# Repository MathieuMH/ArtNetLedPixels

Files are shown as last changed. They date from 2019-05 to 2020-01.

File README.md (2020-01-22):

# ArtNetLedPixels
This is a small project to drive up to +4000 WS28xx LED pixels. It is made for a local free family festival called Copacobana. Which takes place in Ghent (Belgium) every year at the end of June.
As a light operator I like to experiment with budget friendly equipment (like WS28xx leds), to create nice moderate effects. Our club stage is mainly for the afterparty.
This project was used to illuminate the logo of the stage.
The board receives it data from a lighting desk, in our situation (Chamsys MQ500). We mainly use the Art-Net protocol since its quite easy to adopt. The output is driven with the FastLED library.

# Required Hardware
The setup consists of the following hardware:
* Teensy 3.1 or 3.2 (there is basicly no difference for this project)
* Wiznet Wiz850io (LAN tranceived based on the WIZ5000)
* Carrierboard (refer to the ArtNet_WS2812B folder, board is drawn in KiCad 5)

# Output
The board has 12 outputs with screw terminal and one with solder terminal at R14.

# Contributors
Mathieu (THIEU.Gent)
Copacobana Festival http://www.copacobana.be

# License
MIT License

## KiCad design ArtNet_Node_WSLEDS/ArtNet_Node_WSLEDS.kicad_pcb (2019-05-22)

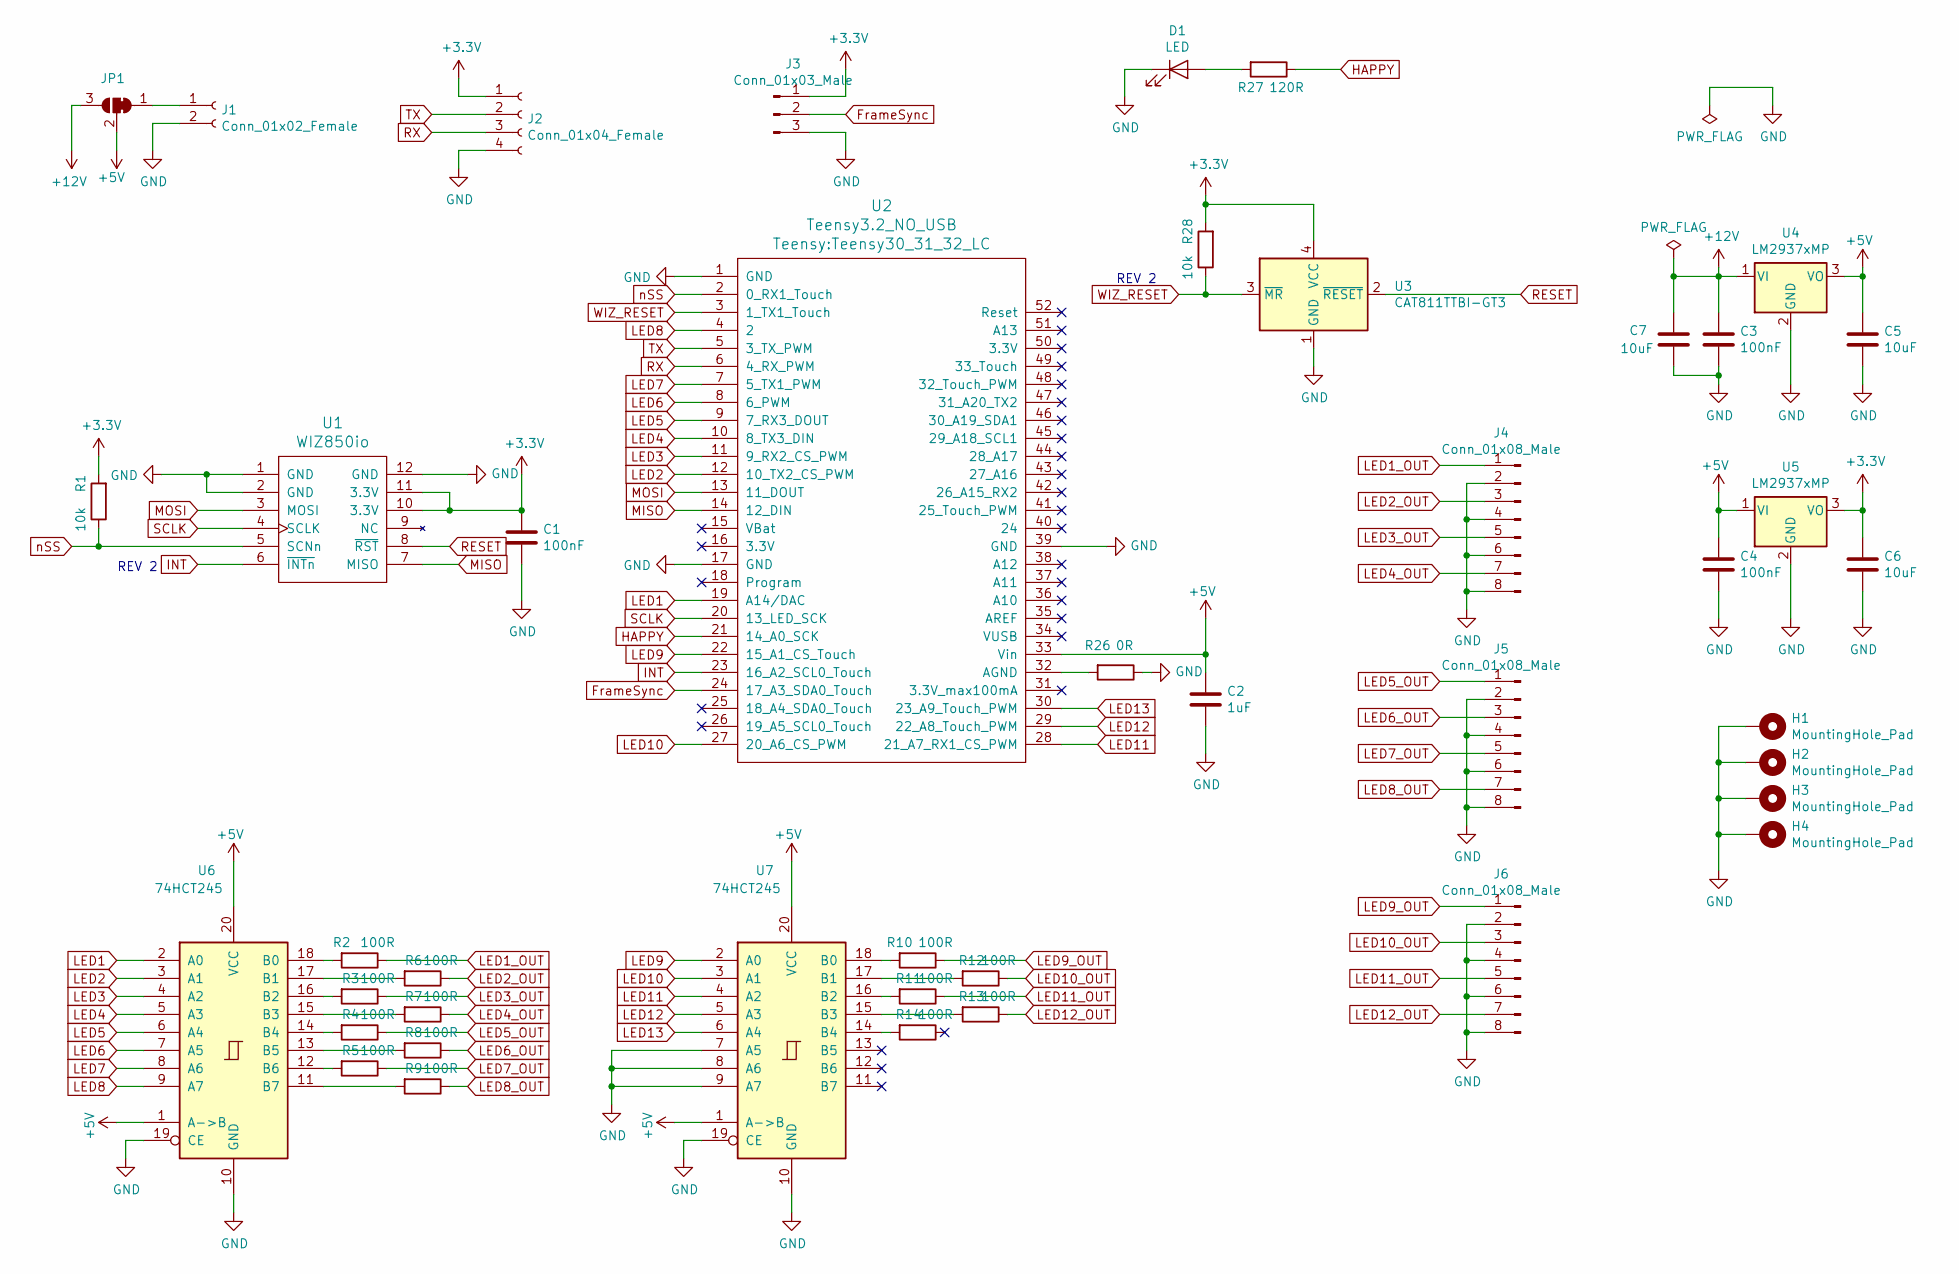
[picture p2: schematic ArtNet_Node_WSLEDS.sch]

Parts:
C1, C3, C4: 100nF; C_0805_HandSoldering
C2: 1uF; C_0805_HandSoldering
C5, C6, C7: 10uF; C_0805_HandSoldering
D1: LED; LED_1206_HandSoldering
H1, H2, H3, H4: MountingHole_Pad; MountingHole_4.3mm_M4_Pad
J1: Conn_01x02_Female; TerminalBlock_Phoenix_MPT-2.54mm_2pol
J2: Conn_01x04_Female; TerminalBlock_Phoenix_MPT-2.54mm_4pol
J3: Conn_01x03_Male; TerminalBlock_Phoenix_MPT-2.54mm_3pol
J4, J5, J6: Conn_01x08_Male; TerminalBlock_Phoenix_MPT-2.54mm_8pol
JP1: SolderJumper_3_Bridged12; SolderJumper-3_P1.3mm_Bridged12_Pad1.0x1.5mm_NumberLabels
R1, R28: 10k; R_1206_HandSoldering
R2, R3, R4, R5, R6, R7, R8, R9, R10, R11, R12, R13, R14: 100R; R_1206_HandSoldering
R26: 0R; R_1206_HandSoldering
R27: 120R; R_1206_HandSoldering
U1: WIZ850io
U2: Teensy3.2_NO_USB; Teensy30_31_32_LC
U3: CAT811TTBI-GT3; SOT-143
U4, U5: LM2937xMP; SOT-223-3_TabPin2
U6, U7: 74HCT245; SO-20_12.8x7.5mm_Pitch1.27mm

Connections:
+3V3: C1.1, C6.1, J2.1, J3.1, R1.2, R28.2, U1.10 (3.3V), U1.11 (3.3V), U3.4 (VCC), U5.3 (VO)
+5V: C2.1, C4.1, C5.1, JP1.2 (C), U2.33 (Vin), U4.3 (VO), U5.1 (VI), U6.1 (A->B), U6.20 (VCC), U7.1 (A->B), U7.20 (VCC)
+12V: C3.1, C7.1, JP1.3 (B), U4.1 (VI)
FrameSync: J3.2, U2.24 (17_A3_SDA0_Touch)
GND: C1.2, C2.2, C3.2, C4.2, C5.2, C6.2, C7.2, D1.1 (K), H1.1, H2.1, H3.1, H4.1, J1.2, J2.4, J3.3, J4.2, J4.4, J4.6, J4.8, J5.2, J5.4, J5.6, J5.8, J6.2, J6.4, J6.6, J6.8, R26.1, U1.1 (GND), U1.2 (GND), U1.12 (GND), U2.1 (GND), U2.17 (GND), U2.39 (GND), U3.1 (GND), U4.2 (GND), U5.2 (GND), U6.10 (GND), U6.19 (CE), U7.7 (A5), U7.8 (A6), U7.9 (A7), U7.10 (GND), U7.19 (CE)
HAPPY: R27.1, U2.21 (14_A0_SCK)
INT: U1.6 (~INTn), U2.23 (16_A2_SCL0_Touch)
LED1: U2.19 (A14/DAC), U6.2 (A0)
LED1_OUT: J4.1, R2.1
LED2: U2.12 (10_TX2_CS_PWM), U6.3 (A1)
LED2_OUT: J4.3, R6.1
LED3: U2.11 (9_RX2_CS_PWM), U6.4 (A2)
LED3_OUT: J4.5, R3.1
LED4: U2.10 (8_TX3_DIN), U6.5 (A3)
LED4_OUT: J4.7, R7.1
LED5: U2.9 (7_RX3_DOUT), U6.6 (A4)
LED5_OUT: J5.1, R4.1
LED6: U2.8 (6_PWM), U6.7 (A5)
LED6_OUT: J5.3, R8.1
LED7: U2.7 (5_TX1_PWM), U6.8 (A6)
LED7_OUT: J5.5, R5.1
LED8: U2.4 (2), U6.9 (A7)
LED8_OUT: J5.7, R9.1
LED9: U2.22 (15_A1_CS_Touch), U7.2 (A0)
LED9_OUT: J6.1, R10.1
LED10: U2.27 (20_A6_CS_PWM), U7.3 (A1)
LED10_OUT: J6.3, R12.1
LED11: U2.28 (21_A7_RX1_CS_PWM), U7.4 (A2)
LED11_OUT: J6.5, R11.1
LED12: U2.29 (22_A8_Touch_PWM), U7.5 (A3)
LED12_OUT: J6.7, R13.1
LED13: U2.30 (23_A9_Touch_PWM), U7.6 (A4)
MISO: U1.7 (MISO), U2.14 (12_DIN)
MOSI: U1.3 (MOSI), U2.13 (11_DOUT)
unnamed: D1.2 (A), R27.2
unnamed: J1.1, JP1.1 (A)
unnamed: R2.2, U6.18 (B0)
unnamed: R3.2, U6.16 (B2)
unnamed: R4.2, U6.14 (B4)
unnamed: R5.2, U6.12 (B6)
unnamed: R6.2, U6.17 (B1)
unnamed: R7.2, U6.15 (B3)
unnamed: R8.2, U6.13 (B5)
unnamed: R9.2, U6.11 (B7)
unnamed: R10.2, U7.18 (B0)
unnamed: R11.2, U7.16 (B2)
unnamed: R12.2, U7.17 (B1)
unnamed: R13.2, U7.15 (B3)
unnamed: R14.2, U7.14 (B4)
unnamed: R26.2, U2.32 (AGND)
RESET: U1.8 (~RST), U3.2 (~RESET)
RX: J2.3, U2.6 (4_RX_PWM)
SCLK: U1.4 (SCLK), U2.20 (13_LED_SCK)
TX: J2.2, U2.5 (3_TX_PWM)
WIZ_RESET: R28.1, U2.3 (1_TX1_Touch), U3.3 (~MR)
nSS: R1.1, U1.5 (SCNn), U2.2 (0_RX1_Touch)

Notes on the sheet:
REV 2

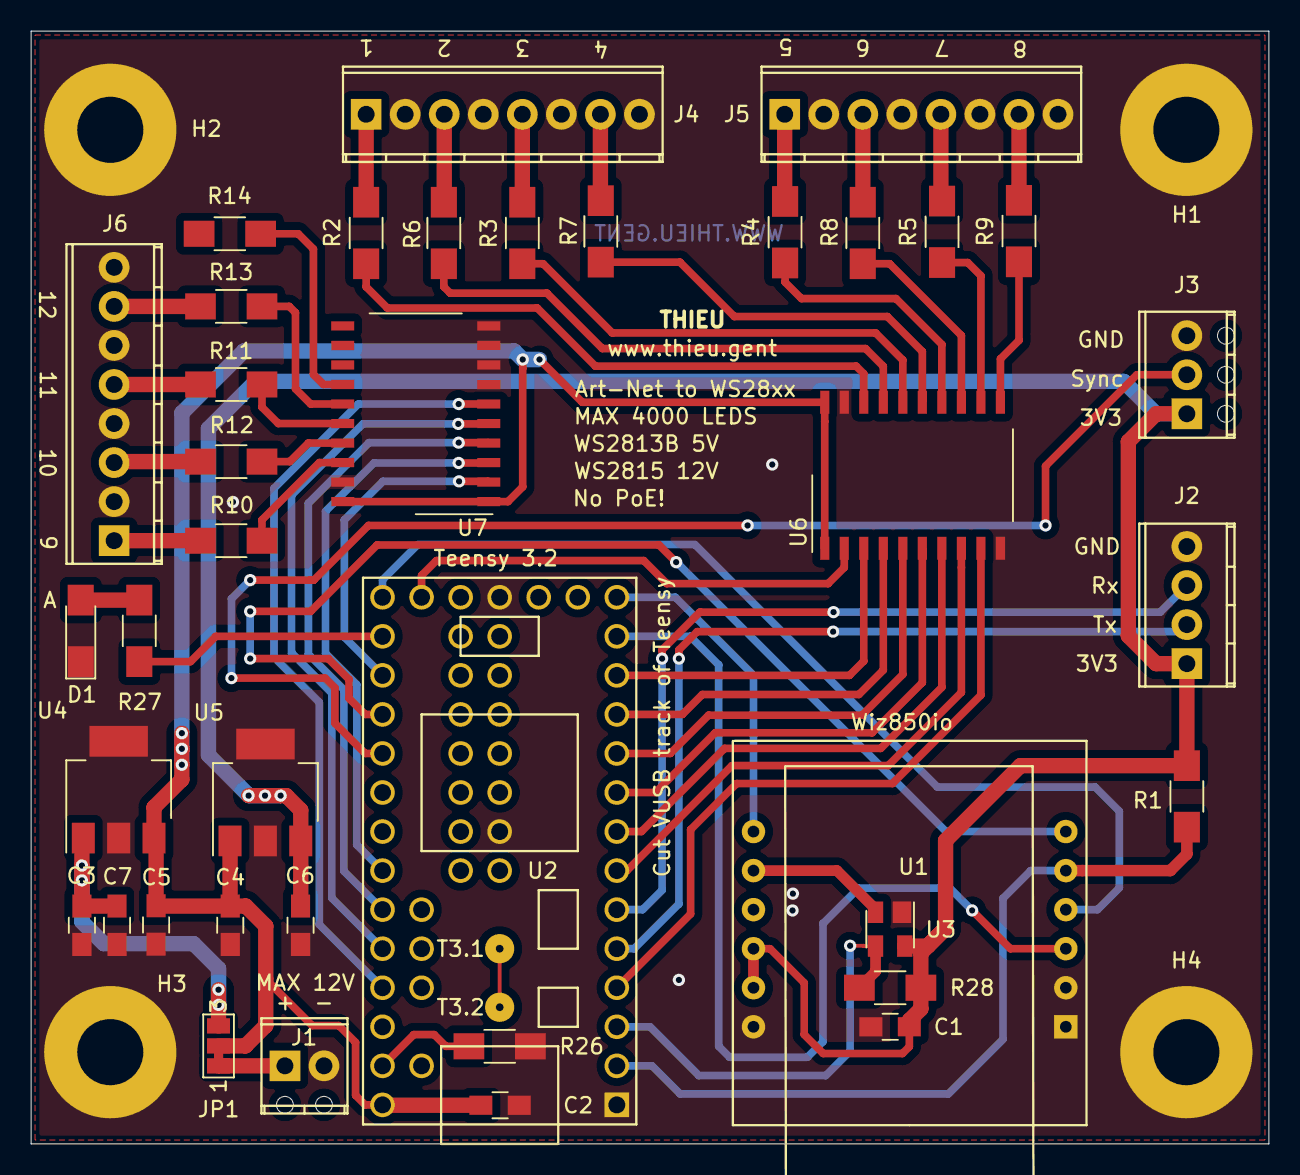
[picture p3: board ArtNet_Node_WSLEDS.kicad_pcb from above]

Board: 2 copper layers, 80.5 x 72.4 mm, 43 parts (0 on the bottom side), 56 nets.

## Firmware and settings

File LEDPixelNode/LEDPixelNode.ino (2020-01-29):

/*H**********************************************************************
* FILENAME :        LEDPixelNode.ino         DESIGN REF: LPXN
*
* DESCRIPTION :
*       This code will receive multiple univers via Art-Net and send
*       it to a multiple WS28xx LED strips.
*
* NOTES :
*       This code is optimized to run on a Teensy 3.x
*       A Wiz850io (or legacy Wiz820io) is used to receive the UPD data.
*       A THIEU designed carrier board to connect everything.
*       
* GIT :
*       https://github.com/MathieuMH/ArtNetLedPixels
*
* AUTHOR :    Mathieu Hebbrecht       START DATE :    22 Januari 2020
*
* CHANGES :
* REF NO  VERSION   DATE        WHO     DETAIL
* LPXN    00.01     22/01/2020  MHT     Initial version
*
* LICENSE :
* MIT license, see the LICENSE file for details
*H*/

#define FASTLED_ALLOW_INTERRUPTS 0
//#define USE_OCTOWS2811
//#include <OctoWS2811.h>
#include <FastLED.h>
#include <Artnet.h>

// --- PIN DEFINITIONS ---
#define LED1          14
#define LED2          10
#define LED3          9
#define LED4          8
#define LED5          7
#define LED6          6
#define LED7          5
#define LED8          2
#define LED9          15
#define LED10         20
#define LED11         21
#define LED12         22
#define LED13         23
#define WIZ_CS        0
#define WIZ_RESET     1
#define WIZ_INT       16
#define HAPPY_LED     13
#define FRAME_SYNC    17
#define UART_RX       4
#define UART_TX       3

// --- GENERIC DEFINITIONS
#define DEBUG                 0       // 0=only operation commands, no debug ; 1=high level debug ; 2=low level debug
#define RELEASE               0       // Significant changes marker (FEATURES)
#define VERSION               1       // Minor change marker (BUG FIXES)
#define HAPPY_PULSE           1000    // HAPPY LED Flash interval
#define NUM_LEDS_PER_STRIP    40      // Number of pixels in each LEDS strip (= output)
#define NUM_LED_STRIPS        1       // Number of strips connected

int inByte = 0;
long previousMillis = 0;
int ledState = HIGH;

// --- FastLED Settings
//CRGB leds[NUM_LEDS_PER_STRIP];
const int numLeds = NUM_LED_STRIPS * NUM_LED_STRIPS;
CRGB leds[numLeds];

// --- Art-Net Settings
Artnet artnet;
int startUniverse = 0;          // Default Artnet universe (in most cases this is 0, but some software require 1 as first)
int previousDataLength = 0;

// --- Network settings
//byte ip[] = {2, 9, 200, 15};
byte broadcast[] = {2, 255, 255, 255};
byte mac[] = {0x72, 0x67, 0xF0, 0xeb, 0x33, 0x30};

void setup()
{
  // - Set pin directions
  //pinMode(HAPPY_LED, OUTPUT);
  pinMode(WIZ_RESET, OUTPUT);
  //pinMode(WIZ_INT, INPUT);
  //pinMode(FRAME_SYNC, INPUT);

    // Port Init
  digitalWrite(WIZ_RESET, LOW);   //Start Wiz850io Reset
  delay(5);
  digitalWrite(WIZ_RESET, HIGH);   //End Wiz850io Reset
  
  // - Serial Init
  Serial.begin(115200);     // For debug and setup
  delay(5);
  Serial.print("LedPixelNode v");
  Serial.print(RELEASE);
  Serial.println("." + VERSION);
  Serial.println( "Compiled: " __DATE__ ", " __TIME__ ", " __VERSION__);
  
  if(DEBUG > 0)
  {  
    while (!Serial) 
    {
      ; // wait for serial port to connect. Needed for native USB port only
    }
    Serial.print("Debug Level is set to: ");
    Serial.println(DEBUG);
  }

  artnet.begin(mac);
  artnet.setBroadcast(broadcast);
  delay(10);

  //Check if Wiz850io is present
  if (Ethernet.hardwareStatus() == EthernetNoHardware) {
    Serial.println("No Wiz850io (or 820io) found. Sorry, can't run without hardware. :(");
    while (true) {
      delay(1); // do nothing, no point running without Ethernet hardware
    }
  }
  if (Ethernet.linkStatus() == LinkOFF) {
    Serial.println("Ethernet cable is not connected.");
  }

    // - FastLed Setup
  FastLED.addLeds<WS2811, LED2>(leds, 0, NUM_LEDS_PER_STRIP);
  //FastLED.addLeds<WS2811, LED2>(leds, NUM_LEDS_PER_STRIP, NUM_LEDS_PER_STRIP);
  //FastLED.addLeds<WS2811, LED3>(leds, NUM_LEDS_PER_STRIP, NUM_LEDS_PER_STRIP);
  //FastLED.addLeds<WS2811, LED4>(leds, NUM_LEDS_PER_STRIP, NUM_LEDS_PER_STRIP);
//  FastLED.addLeds<WS2812B, LED5>(leds, NUM_LEDS_PER_STRIP, NUM_LEDS_PER_STRIP);
//  FastLED.addLeds<WS2812B, LED6>(leds, NUM_LEDS_PER_STRIP, NUM_LEDS_PER_STRIP);
//  FastLED.addLeds<WS2812B, LED7>(leds, NUM_LEDS_PER_STRIP, NUM_LEDS_PER_STRIP);
//  FastLED.addLeds<WS2812B, LED8>(leds, NUM_LEDS_PER_STRIP, NUM_LEDS_PER_STRIP);
//  FastLED.addLeds<WS2812B, LED9>(leds, NUM_LEDS_PER_STRIP, NUM_LEDS_PER_STRIP);
//  FastLED.addLeds<WS2812B, LED10>(leds, NUM_LEDS_PER_STRIP, NUM_LEDS_PER_STRIP);
//  FastLED.addLeds<WS2812B, LED11>(leds, NUM_LEDS_PER_STRIP, NUM_LEDS_PER_STRIP);
//  FastLED.addLeds<WS2812B, LED12>(leds, NUM_LEDS_PER_STRIP, NUM_LEDS_PER_STRIP);
//  FastLED.addLeds<WS2812B, LED13>(leds, NUM_LEDS_PER_STRIP, NUM_LEDS_PER_STRIP);    //Solder pad at R14
  if(DEBUG > 0)
    Serial.println("Enabled 4 FastLED outputs.");

  // - Init test
  startUpTest();

  // this will be called for each packet received
  artnet.setArtDmxCallback(onDmxFrame);
  //artnet.setArtSyncCallback(onSync);
}

void loop()
{
  // *** Art-Net Reading ***
  artnet.read();

//  // *** HAPPY LED ***
//  unsigned long currentMillis = millis();
//  
//  if(currentMillis - previousMillis > HAPPY_PULSE) 
//  {
//    previousMillis = currentMillis;   
//    
//    if (ledState == LOW)
//      ledState = HIGH;
//    else
//      ledState = LOW;
//    
//    digitalWrite(HAPPY_LED, ledState);
//  }
}

void onDmxFrame(uint16_t universe, uint16_t length, uint8_t sequence, uint8_t* data, IPAddress remoteIP)
{
  // read universe and put into the right part of the display buffer
  for (int i = 0; i < length / 3; i++)
  {
    int led = i + (universe - startUniverse) * (previousDataLength / 3);
    if (led < numLeds) {
      leds[i] = CRGB( data[i * 3], data[i * 3 + 1], data[i * 3 + 2]);
      if(DEBUG >= 3)
      {
        Serial.print("onDmxFrame:: LED");
        Serial.print(i*3);
        Serial.print(" R");
        Serial.print(leds[i].red);
        Serial.print(" G");
        Serial.print(leds[i].green);
        Serial.print(" B");
        Serial.println(leds[i].blue);
      }
    }

  }
  previousDataLength = length;

  if(DEBUG == 1)
    Serial.println("F");
  if(DEBUG == 2)
  {
    Serial.print("onDmxFrame:: Frame received. Length: ");
    Serial.println(previousDataLength);
  }
  //In case no sync is receive we do it here. This is assynchronious.
  FastLED.show();
}

void onSync(IPAddress remoteIP) 
{   
    //This is for synchronious output.
    FastLED.show();
    
    if(DEBUG >= 1)
      Serial.println("S");
    if(DEBUG >= 2)
      Serial.println("onSync:: Sync CMD received.");
}

void startUpTest() 
{
  for(int i = 0 ; i < numLeds ; i++)
    leds[i] = CRGB::Red;
  FastLED.show();
  if(DEBUG > 0)
    Serial.println("StartUpTest:: leds::RED");
    
  delay(500);
  for(int i = 0 ; i < numLeds  ; i++)
    leds[i] = CRGB::Green;
  FastLED.show();
  if(DEBUG > 0)
    Serial.println("StartUpTest:: leds::GREEN");
    
  delay(500);
  for(int i = 0 ; i < numLeds  ; i++)
    leds[i] = CRGB::Blue;
  FastLED.show();
  if(DEBUG > 0)
    Serial.println("StartUpTest:: leds::BLUE");
    
  delay(500);
  for(int i = 0 ; i < numLeds  ; i++)
    leds[i] = CRGB::Black;
  FastLED.show();
  if(DEBUG > 0)
    Serial.println("StartUpTest:: END, all leds cleared.");
}

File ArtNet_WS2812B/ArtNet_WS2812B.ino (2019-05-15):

/*
This example will receive multiple universes via Artnet and control a strip of ws2811 leds via
Paul Stoffregen's excellent OctoWS2811 library: https://www.pjrc.com/teensy/td_libs_OctoWS2811.html
This example may be copied under the terms of the MIT license, see the LICENSE file for details
*/

#include <Artnet.h>
#include <Ethernet.h>
#include <EthernetUdp.h>
#include <SPI.h>
#include <OctoWS2811.h>
#include <EEPROM.h>

#define NUM_OF_BYTES_SERIAL 4       //Default length to read out the serial buffer.
#define DEBUG 1
#define PIN_nSS  10
#define PIN_RESET  9
                 
//EEPROM MAP
#define ADDR_IP 0                   //Start address of the IP address
#define ADDR_BC 4                   //Start address of the boardcast address
#define ADDR_MAC 8                  //Start address of the MAC address
#define ADDR_LEDS_PER_STRIP 14      //Address of the number of leds per strip. (max 1000)
#define ADDR_LEDS_STRIPS 16         //Address of the start number of led strips (outputs). Maximum of 8 outputs.
#define ADDR_START_UNIVERSES 18     //Address of the start universe

// OctoWS2811 settings
const int ledsPerStrip = 240; // change for your setup
const byte numStrips= 2; // change for your setup
const int numLeds = ledsPerStrip * numStrips;
const int numberOfChannels = numLeds * 3; // Total number of channels you want to receive (1 led = 3 channels)
DMAMEM int displayMemory[ledsPerStrip*6];
int drawingMemory[ledsPerStrip*6];
const int config = WS2811_GRB | WS2811_800kHz; //or WS2813_800kHz since it uses a different frame set delay.
OctoWS2811 leds(ledsPerStrip, displayMemory, drawingMemory, config);

// Artnet settings
Artnet artnet;
const int startUniverse = 0; // CHANGE FOR YOUR SETUP most software this is 1, some software send out artnet first universe as 0.

// Check if we got all universes
const int maxUniverses = numberOfChannels / 512 + ((numberOfChannels % 512) ? 1 : 0);
bool universesReceived[maxUniverses];
bool sendFrame = 1;
int previousDataLength = 0;
char serialBuffer[NUM_OF_BYTES_SERIAL];

// Change ip and mac address for your setup
byte ip[] = {2, 9, 200, 50};
byte broadcast[] = {2, 9, 200, 255};
byte mac[] = {0xFE, 0xB7, 0xBF, 0x4C, 0xB6, 0x41};

// ---- Prototypes
void checkForSerial();
void printMenu();
void EEPROM_IPAdress(boolean , byte , byte*);
void EEPROM_MACAdress(boolean , byte , byte*);

void setup()
{
  if(DEBUG)
  {
  Serial.begin(115200);
  Serial.println("THIEU Art-Net node 8xWS2813 strip");
  Serial.println("Loading settings from EEPROM");
  }

  pinMode(PIN_RESET, OUTPUT);       // define reset pin as output
  digitalWrite(PIN_RESET, LOW);     // begin reset the WIZ850io
  pinMode(PIN_nSS, OUTPUT);         // define nSS(chip select) as output
  digitalWrite(PIN_nSS, HIGH);      // de-select WIZ850io
  digitalWrite(PIN_RESET, HIGH);    // end reset pulse
  //digitalWrite(PIN_nSS, LOW);     // select WIZ850io
  
  artnet.setBroadcast(broadcast);
  artnet.begin(mac, ip);
  //leds.begin();
  leds.begin(ledsPerStrip, displayMemory, drawingMemory, config);
  initTest();

  // Check for Ethernet hardware present
  if (Ethernet.hardwareStatus() == EthernetNoHardware) {
    Serial.println("Ethernet shield was not found.  Sorry, can't run without hardware. :(");
    while (true) {
      delay(1); // do nothing, no point running without Ethernet hardware
    }
  }
  if (Ethernet.linkStatus() == LinkOFF) {
    Serial.println("Ethernet cable is not connected.");
  }
  
  // this will be called for each packet received
  artnet.setArtDmxCallback(onDmxFrame);
}

void loop()
{
  // we call the read function inside the loop
  artnet.read();
  //checkForSerial();  //Verify if any command is send through the serial connection.
}

void checkForSerial() 
{
  
  if(Serial.available())
  {
    int bytesReceived = Serial.readBytes(serialBuffer, NUM_OF_BYTES_SERIAL);

    if(bytesReceived > 0) 
    {
      switch(serialBuffer[0])
      {
        case 'i':
        case 'I':
          //set IP ADDRESS
          break;
  
        case 'm':
        case 'M':
          //set MAC ADDRESS
          break;
  
        case 'b':
        case 'B':
          //set broadcast ADDRESS
          break;
  
        case 'l':
        case 'L':
          //set number of leds per strip
          break;
  
        case 's':
        case 'S':
          //set number of strips
          break;
  
        case 'u':
        case 'U':
          //set start universe
          break;
          
        case '?':
        default: printMenu();
          break;
      }
    }
  }
}

void printMenu() 
{
  Serial.print("The available commands are:");
  Serial.println("");
}

void EEPROM_IPAdress(boolean WRITE, byte EEPROM_ADDRESS, byte* IP_ADDRESS) {
  if(WRITE) 
  {
    for(int i=0 ; i < 4 ; i++) 
    {
      EEPROM.write(EEPROM_ADDRESS+i, IP_ADDRESS[i]);
    }
  } else 
  {
    for(int i=0 ; i < 4 ; i++) 
    {
      IP_ADDRESS[i] = EEPROM.read(EEPROM_ADDRESS+i);
    }
  }
}

void EEPROM_MACAdress(boolean WRITE, byte EEPROM_ADDRESS, byte* MAC_ADDRESS) 
{
  if(WRITE) 
  {
    for(int i=0 ; i < 6 ; i++)
    {
      EEPROM.write(EEPROM_ADDRESS+i, MAC_ADDRESS[i]);
    }
  } else {
    for(int i=0 ; i < 6 ; i++) 
    {
      MAC_ADDRESS[i] = EEPROM.read(EEPROM_ADDRESS+i);
    }
  }
}

void onDmxFrame(uint16_t universe, uint16_t length, uint8_t sequence, uint8_t* data, IPAddress remoteIP)
{
  sendFrame = 1;

  // Store which universe has got in
  if ((universe - startUniverse) < maxUniverses)
    universesReceived[universe - startUniverse] = 1;

  for (int i = 0 ; i < maxUniverses ; i++)
  {
    if (universesReceived[i] == 0)
    {
      sendFrame = 0;
      break;
    }
  }

  // read universe and put into the right part of the display buffer
  for (int i = 0; i < length / 3; i++)
  {
    int led = i + (universe - startUniverse) * (previousDataLength / 3);
    if (led < numLeds)
      leds.setPixel(led, data[i * 3], data[i * 3 + 1], data[i * 3 + 2]);
  }
  previousDataLength = length;

  if (sendFrame)
  {
    leds.show();
    // Reset universeReceived to 0
    memset(universesReceived, 0, maxUniverses);
  }
}

void initTest()
{
  for (int i = 0 ; i < numLeds ; i++)
    leds.setPixel(i, 127, 0, 0);
  leds.show();
  delay(500);
  for (int i = 0 ; i < numLeds  ; i++)
    leds.setPixel(i, 0, 127, 0);
  leds.show();
  delay(500);
  for (int i = 0 ; i < numLeds  ; i++)
    leds.setPixel(i, 0, 0, 127);
  leds.show();
  delay(500);
  for (int i = 0 ; i < numLeds  ; i++)
    leds.setPixel(i, 0, 0, 0);
  leds.show();
}

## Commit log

2019-05-08 Initial version
    First (untested release) of PCB files and arduino code. Serial communication not working.
    [ArtNet_Node_WSLEDS-B_Cu.gbl, ArtNet_Node_WSLEDS-B_Mask.gbs, ArtNet_Node_WSLEDS-B_SilkS.gbo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]
2019-05-22 Update the PCB design;
    Migration to FastLED library (more reliable). And 4 more outputs which makes is 12 in total (+1 if soldered to R14).
    Also change the output driver to 74HCT245. The mosfet solution was not working very on fast speeds.
    [ArtNet_Node_WSLEDS-B_Cu.gbl, ArtNet_Node_WSLEDS-B_Mask.gbs, ArtNet_Node_WSLEDS-B_SilkS.gbo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]
2020-01-13 Update sync
    Updates the files. Still not working!
    [LEDPixelNode.ino]
2020-01-22 Update ArtNet_Node_WSLEDS.sch
    Added a schematic remark
    [ArtNet_Node_WSLEDS.sch]
